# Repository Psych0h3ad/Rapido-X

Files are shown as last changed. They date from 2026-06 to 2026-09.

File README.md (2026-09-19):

# Rapido X

## P3D STEP files — English

The P3D front and rear parts feature a structure designed to make cable routing easier and gentler on the cables than the version released by Phaetus.

[See the illustrated P3D vs. Phaetus comparison](docs/P3D-vs-Phaetus.md), including a close-up of the front cable-routing cutout, the rear opening and the top-hole layout. An [experimental heatsink-cooling CFD comparison](docs/cooling/README.md) is also available.

**I am not a specialist in thermodynamics or fluid mechanics; please treat the simulation results as reference material only.** They use simplified assumptions and have not been validated by physical tests.

- [SB Front Rapido X_P3D.STEP](SB%20Front%20Rapido%20X_P3D.STEP) — Front part
- [SB Rear CW2 Rapido X_P3D.STEP](SB%20Rear%20CW2%20Rapido%20X_P3D.STEP) — Rear part for CW2

## P3D STEPファイル — 日本語

P3D版のフロント・リアパーツは、Phaetusが公開したバージョンと比べて、ケーブルを取り回しやすく、ケーブルに優しい構造になっています。

[P3D版とPhaetus公式版の図解比較](docs/P3D-vs-Phaetus.md)では、フロントのケーブル用切り欠きの拡大図に加え、リア開口部・上面の穴配置の違いを確認できます。[ヒートシンク冷却の試験的なCFD比較](docs/cooling/README.md)も掲載しています。

**私は熱力学・流体力学の専門家ではありませんので、解析結果は参考程度にご覧ください。** 簡略化した仮定に基づく結果であり、実機試験による検証は行っていません。

- [SB Front Rapido X_P3D.STEP](SB%20Front%20Rapido%20X_P3D.STEP) — フロントパーツ
- [SB Rear CW2 Rapido X_P3D.STEP](SB%20Rear%20CW2%20Rapido%20X_P3D.STEP) — CW2用リアパーツ

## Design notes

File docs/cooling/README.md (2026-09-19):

# Rapido X: P3D / Phaetus exploratory cooling comparison

2026-09-20 · OpenFOAM v2412 · SIBOOR 4010 fan installation

> **Experimental results — for reference only / 試験的な結果・参考資料**
>
> I am not a specialist in thermodynamics or fluid mechanics. Please treat this AI-assisted, exploratory CFD comparison as reference material only. It uses simplified assumptions and has not been validated by physical tests or independently reviewed by a specialist. It does not establish real-world cooling performance or a guaranteed temperature reduction.
>
> 私は熱力学・流体力学の専門家ではありません。このAI支援による試験的なCFD比較は、参考程度にご覧ください。簡略化した仮定に基づく結果であり、実機試験による検証や専門家による独立したレビューは行っていません。実機の冷却性能や温度低下を保証するものではありません。

## 日本語

**今回の仮定では、P3D版の方がヒートシンクから熱を逃がしやすい結果でした。** 同じ送風圧力で比較した放熱コンダクタンスは、25 Paで公式版より約27%高く、追加した10 Pa・50 Paの条件でも同じ傾向でした。これは実測したファン特性による性能保証や、実機の温度低下率を表すものではありません。

流れの残差は設定した収束目標に達しておらず、メッシュ独立性も未検証です。**統合した流量・放熱指標を使った探索的な比較**として扱ってください。細部の速度や実機の温度を断定する用途には使えません。

### 比較結果

同じRapido UHF用の長いMain Bodyと同じRapido X外形を使用し、フロント・リアの取り付け部品を入れ替えました。表内の数値は「Phaetus公式 / P3D」の順です。

| 仮定したファン全圧 | 入口流量 L/min（公式 / P3D） | 放熱能力 H, W/K（公式 / P3D） | P3DのHの差 |
|---|---:|---:|---:|
| 10 Pa | 39.7 / 37.9 | 0.253 / 0.323 | +28.0% |
| 25 Pa | 67.2 / 65.3 | 0.366 / 0.467 | +27.3% |
| 50 Pa | 99.1 / 97.2 | 0.473 / 0.598 | +26.4% |

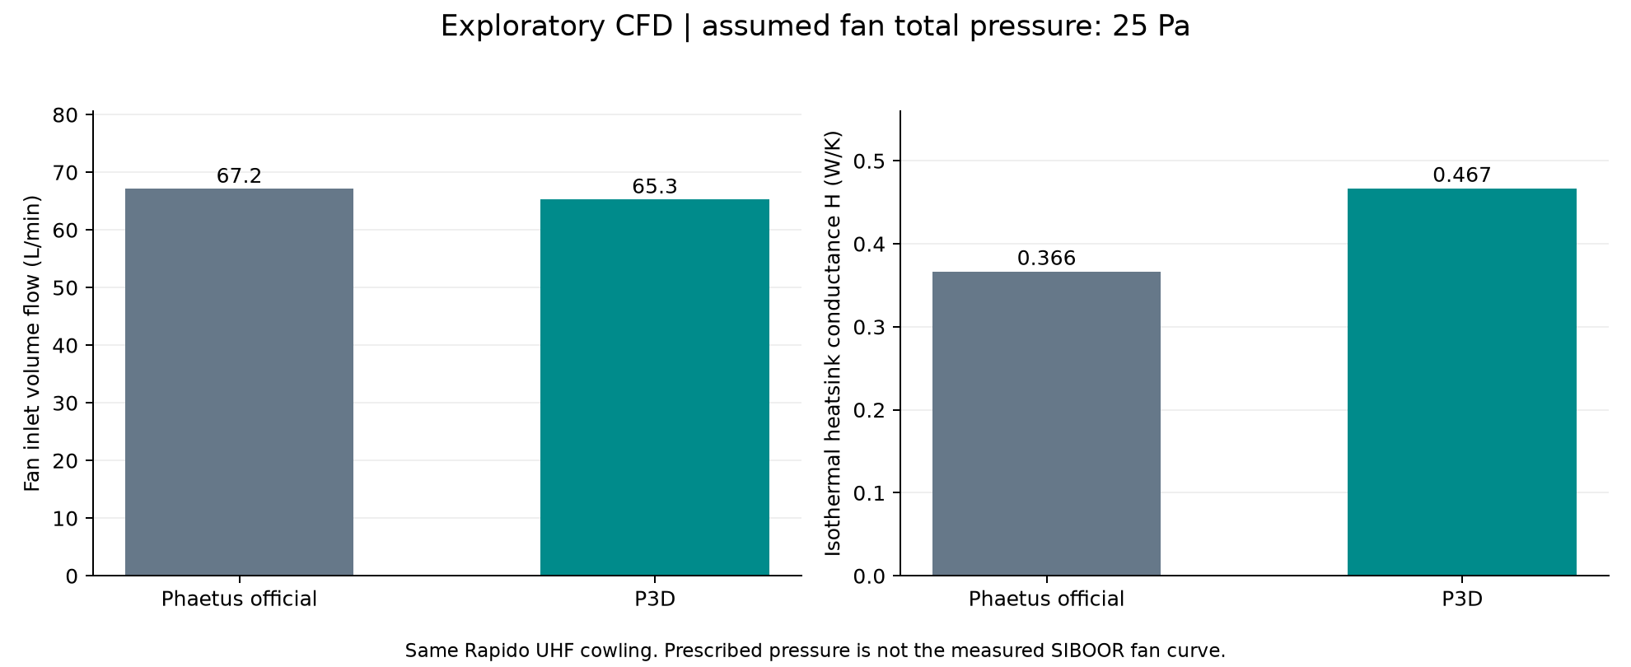
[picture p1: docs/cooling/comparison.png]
25Pa comparison


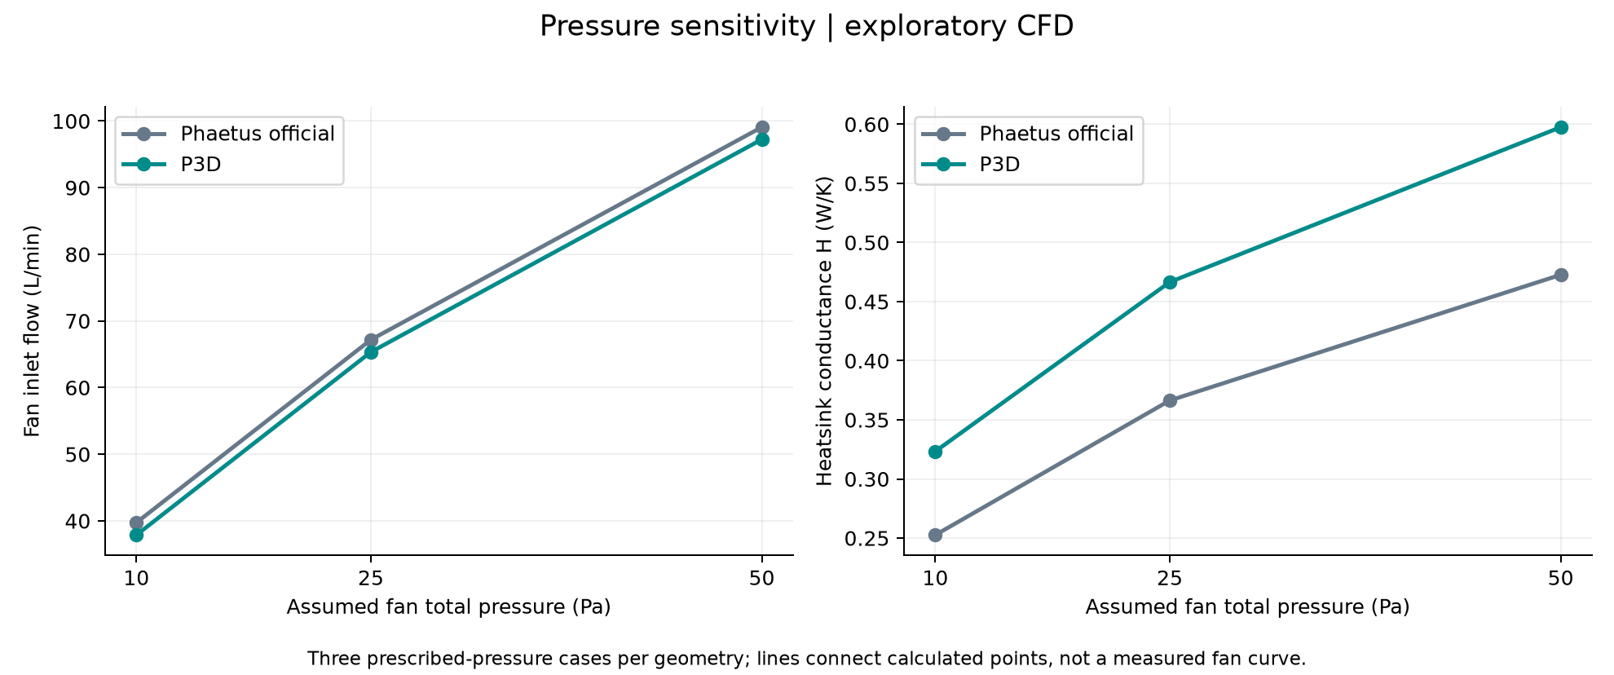
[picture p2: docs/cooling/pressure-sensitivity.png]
Pressure sensitivity


Hは、ヒートシンクと周囲の温度差1 Kあたりに空気へ逃がせる熱量を表します。計算ではヒートシンク表面を一様温度とし、`Q = H × (T_sink − T_ambient)` として比較しています。温度低下率やヒーター出力そのものではありません。

P3D版の空気に露出するヒートシンク面積は、このメッシュでは約13.4%大きくなっています。総風量の多少だけで放熱能力は決まらず、露出面積、フィン周囲への風の届き方、排気経路が合わせて影響しています。今回比較したのは前後の部品全体であり、[形状比較で示したケーブル用切り欠き](../P3D-vs-Phaetus.md)だけの効果を分離した計算ではありません。

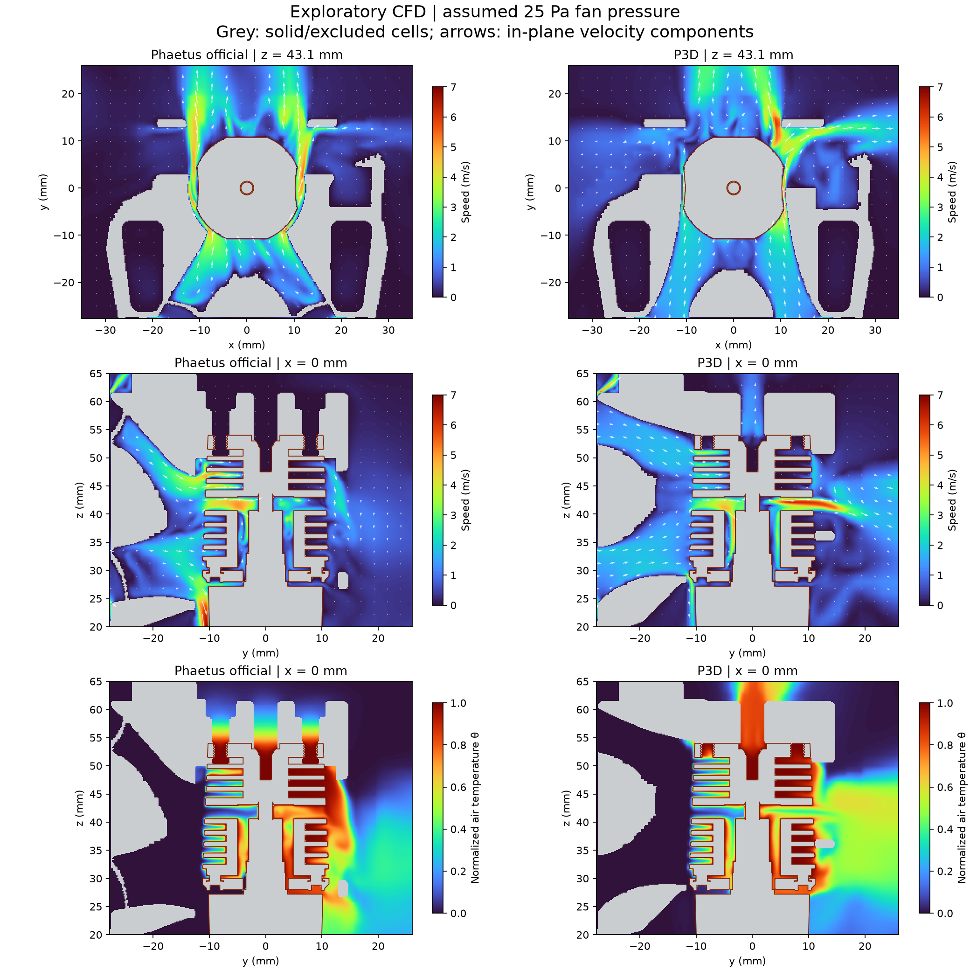
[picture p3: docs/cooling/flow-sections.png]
Flow and normalized temperature sections


断面図の矢印は3次元速度の断面内成分です。粒子の軌跡を表すものではありません。灰色は固体または計算対象外の領域、θは周囲0・ヒートシンク表面1に正規化した空気温度です。

### ブロック温度250℃・300℃との関係

250℃・300℃はヒーターブロック側の条件としました。ヒートシンク全体をこの温度にはしていません。公開STEPは材質境界まで分かれた熱解析用アセンブリではないため、ヒートブレイクや接触部の熱抵抗を直接確定できません。

そこで、CFDで得たHを使い、ブロックからヒートシンクへの熱の伝わりやすさGを変えた単純な熱回路を示します。

`T_sink = (G × T_block + H × T_ambient) / (G + H)`

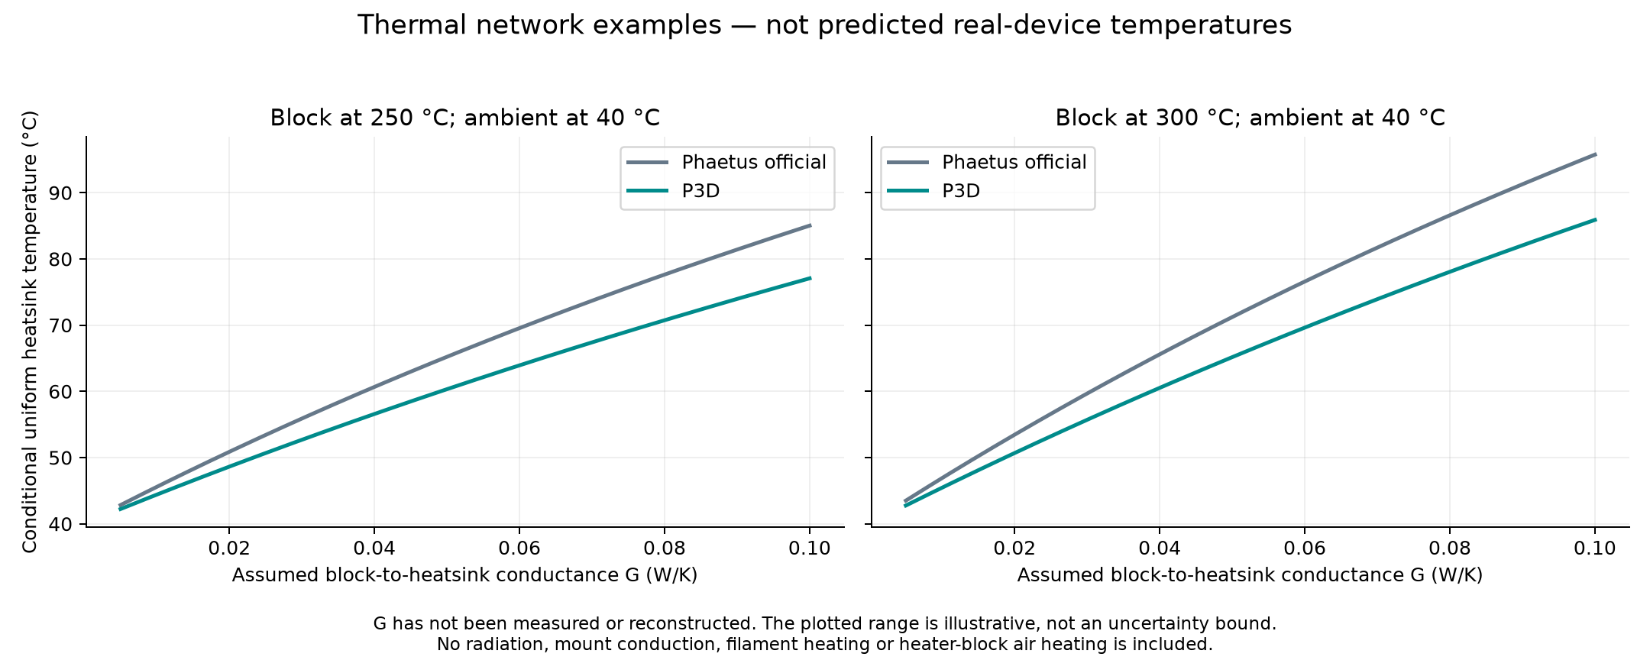
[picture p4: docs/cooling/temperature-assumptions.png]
Conditional temperature examples


例えば、**G=0.020 W/Kと仮定した場合だけ**の値は下表です。Gは実測値でもCADから復元した値でもなく、グラフの範囲も実機の誤差範囲を意味しません。周囲温度は40℃、ファン条件は25 Paです。

| ブロック | 公式の仮定温度 | P3Dの仮定温度 | 仮定上の差 |
|---|---:|---:|---:|
| 250°C | 50.9°C | 48.6°C | 2.2°C |
| 300°C | 53.5°C | 50.7°C | 2.8°C |

120 Wは板状セラミックヒーターの定格であり、温度制御中に常時120 Wがヒートシンクへ流入する設定にはしていません。上の値は連成熱伝導解析で求めた実機温度ではありません。

### 計算条件と限界

- ファンはユーザー指定のSIBOOR `4010-2401-8000-SS`、24 V・0.1 A、約8000 rpmを想定。実測P–Q曲線は入手できていないため、10/25/50 Paを仮定した圧力入口で比較しました。羽根回転・旋回流・実際の動作点は再現していません。
- 4010モデルの出口位置に、外半径18.5 mm・ハブ半径9 mmの環状入口を設定。寸法は汎用CADを基にした近似です。
- 周囲40℃、密度1.13 kg/m³、動粘度1.7×10⁻⁵ m²/s、比熱1006 J/(kg K)、Pr=0.71、乱流Pr=0.85を使用。一定物性の非圧縮・強制対流モデルです。
- 等温の冷却対象面は、組立座標で x/y=±20 mm、z=30.49–54.01 mmに入るホットエンド表面を選択したヒートシンク代表領域です。下端の接続部を含む残りのホットエンド外形は断熱としており、全外表面の放熱量ではありません。
- `simpleFoam`、定常RANS k–ω SST。25 Paは500反復、10/50 Paはスケーリングした25 Paの場から120反復。温度場は各条件の流れを固定し、さらに収束させています。
- 固体内部の熱伝導、接触熱抵抗、放射、浮力、ヒーターブロックから空気への直接放熱、フィラメントへの熱流を含みません。ヒートシンクは一様温度面として扱い、アルミの具体的な熱伝導率を解いていません。
- 配線、取り付けねじ、PTFEチューブ、押出機周りの追加の遮蔽物は再現していません。5015のパーツ冷却の送風・ファン形状も含みません。実際の組み立て状態による閉塞は、特に大きい開口の効果を変える可能性があります。
- 外部領域は x=±55、y=−27.9〜45、z=−22〜82 mmで、UHFボディ上部は領域外です。領域寸法の感度は未検証です。
- Phaetus仕様ではヒーターブロックはニッケルめっき銅合金、ヒートブレイクはステンレス＋EndCoatです。この仕様情報を、固体の材質別連成解析を実施したという意味には用いていません。

### 数値検証

| 項目 | 結果 |
|---|---|
| セル数 | 公式 1,897,926 / P3D 2,041,284 |
| フィン付近の基準セル幅 | 約0.25 mm。境界層プリズム層なし |
| 最大非直交角 | 公式66.24° / P3D63.21° |
| メッシュ警告 | 両モデル各1個の高skewness面（約7.77）。標準checkMeshは1項目未合格 |
| 警告位置 | P3Dでは x≈28.7, y≈−2.37, z≈16.3 mm。ヒートシンク領域の外側 |
| 全6条件の最大流量収支誤差 | 0.0066% |
| 全6条件の最大熱収支誤差 | 0.0116% |
| 追加収束したθの最大最終初期残差 | 9.02e-09 |
| 最後の6記録の最大入口流量変動幅 | 0.205% |
| 最後の6記録の最大放熱モニター変動幅 | 0.512%（追加温度収束前） |

流れの残差目標1e−5は全項目で達成しておらず、周囲の再循環に揺れが残ります。上記の変動幅は反復間の安定性であり、実機に対する誤差率ではありません。別解像度でのメッシュ独立性試験、ファン曲線による動作点の検証、実機温度との照合は未実施です。

入力メッシュは小さい穴や継ぎ目を修復しています。フロント修復による体積差は0.02%未満、修復面から原形状へのサンプル最大距離はP3D約0.188 mm、公式約0.269 mmでした。ホットエンドの修復では内部ボア付近に最大約1.80 mmの差があるサンプルがあり、体積差は約0.136 mm³でした。これらはサンプル評価であり、厳密な誤差上限ではありません。元のSTEP/3MFを変更していません。

### 実機で確認するなら

同じファン・同じ電圧、同じチャンバー温度、同じ配線経路で、ブロック250℃と300℃それぞれの安定後にヒートシンクの同じ位置を測ると、この比較の方向を検証できます。今回のCFDだけから、実機で何℃下がるか、ヒートクリープが必ず解消するかは判断できません。

## English

**Under the assumptions tested here, the P3D assembly has higher isothermal heatsink-to-air conductance than the Phaetus assembly.** At an assumed fan total pressure of 25 Pa, the calculated difference is approximately 27%. The direction remains the same at 10 and 50 Pa. This is an exploratory result, not a validated performance claim for the actual SIBOOR fan.

The table above reports inlet volume flow and conductance H; each pair is **Phaetus / P3D**. H relates heat removal to heatsink-to-ambient temperature difference through `Q = H(T_sink − T_ambient)`. It is not a percentage reduction in operating temperature.

Both assemblies use the same long Rapido UHF cowling and Rapido X outer geometry. The entire front/rear mount pair is exchanged, so this study does not isolate the effect of only the highlighted cable cutout. The P3D case exposes more heatsink surface to air. Actual wires, fasteners, PTFE tubing and additional extruder obstructions are omitted.

The fan is represented by a prescribed annular pressure inlet. The tested 10/25/50 Pa values are assumptions, not a measured P–Q curve or an 8000 rpm rotor simulation. Air is modeled at 40°C using steady incompressible k–ω SST RANS. The isothermal sink region is selected from hotend faces within x/y=±20 mm and z=30.49–54.01 mm; the remaining hotend envelope, including the lower connection region, is adiabatic. Each temperature field is additionally converged on its frozen flow field, with a maximum heat balance discrepancy of 0.0116% across the six cases.

The 250°C and 300°C heater-block conditions are illustrated with a separate lumped thermal network using the CFD conductance. The block-to-heatsink conductance G is unknown. The temperature plot and example table therefore show **conditional scenarios, not predicted device temperatures**. The 120 W ceramic-heater rating is not treated as continuous heatsink heat input. Solid conduction, contact resistances, radiation, buoyancy and direct heater-block heating of the air are omitted.

The specified flow residual target was not reached, and mesh independence and experimental validation have not been demonstrated. One high-skewness face is flagged in each mesh; other reported mesh checks pass. Integrated quantities stabilize, but residual recirculation fluctuations remain. These limitations must accompany any reuse of the numbers or figures.

## Sources and files

- [User repository and CAD](https://github.com/Psych0h3ad/Rapido-X): `SB Front Rapido X_P3D.STEP`, `SB Rear CW2 Rapido X_P3D.STEP`, `Rapido X.STEP`, `Rapido X-voron.3mf`.
- Official comparison meshes: `3D/Objects/object_2.model` mesh 1 (front), `3D/Objects/object_3.model` mesh 3 (rear), within the supplied Phaetus 3MF.
- [Voron Stealthburner CAD](https://github.com/VoronDesign/Voron-Stealthburner/tree/8bcb9c246fac19d8ac03931ef97fa07c5e5f0f2b/CAD): 4010 fan position/reference geometry.
- [Rapido UHF long cowling](https://github.com/VoronDesign/VoronUsers/tree/8e5067f4f6457da8a552983dd210ec48c40be2ca/printer_mods/bythorsthunder/Stealthburner_Rapido_Uhf): bythorsthunder's VoronUsers mod.
- [Phaetus Rapido X specifications](https://www.phaetus.com/products/rapido-x): heater and material information.
- [SIBOOR bill of materials](https://docs.siboor.com/siboor-trident-june/bill-of-materials): 24 V / 8000 rpm 4010 fan reference, not an exact-part pressure curve.
- [OpenFOAM scalar transport documentation](https://api.openfoam.com/2312/classFoam_1_1functionObjects_1_1scalarTransport.html): passive scalar transport with molecular/turbulent diffusivity.
- [metrics.json](metrics.json): 25 Pa values.
- [pressure-sensitivity.csv](pressure-sensitivity.csv) / [JSON](pressure-sensitivity.json): all six runs.
- [assumptions.json](assumptions.json) and [source-manifest.json](source-manifest.json): assumptions and input file hashes.
- [Validation records](validation/README.md): solver, mesh and thermal-balance records; machine hostname and local workspace path have been redacted.
- [simulation-inputs.zip](simulation-inputs.zip): geometry, settings and a run script for rebuilding the comparison. This reproduces the setup with OpenFOAM v2412; the original baseline initially used v1912, so the archive does not promise a bit-for-bit identical iteration history.

Photographs of the physical assembly were used as setup references and are not included here.

[Back to repository README / リポジトリのREADMEに戻る](../../README.md)

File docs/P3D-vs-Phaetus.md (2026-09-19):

# P3D vs. Phaetus: cable-routing geometry
# P3D版とPhaetus公式版：ケーブル取り回しに関わる形状の比較

The P3D parts are designed to make cable routing easier and gentler on the cables than the Phaetus version. The main feature highlighted here is the **front-side cutout directly above the lower mounting hole**, shown on the left side of the part in the interior view below. The rear part also has a large side cutout.

P3D版は、Phaetus公式版よりケーブルを取り回しやすく、ケーブルに優しい構造を目指しています。特に注目しているのは、**フロントの下側取付穴のすぐ上にある側面の切り欠き**です。下の内側から見た図ではパーツの左側にあたります。リア側にも大きな側面切り欠きがあります。

Here, **Phaetus** means the VORON parts contained in this repository's [Rapido X-voron.3mf](../Rapido%20X-voron.3mf). **P3D** means the two STEP files linked below. This comparison applies to these specific files.

本資料の **Phaetus公式版** は、このリポジトリの [Rapido X-voron.3mf](../Rapido%20X-voron.3mf) に含まれるVORON用パーツを指します。**P3D版** は下記2点のSTEPファイルです。比較対象はこれらのファイルに限定しています。

- [SB Front Rapido X_P3D.STEP](../SB%20Front%20Rapido%20X_P3D.STEP)
- [SB Rear CW2 Rapido X_P3D.STEP](../SB%20Rear%20CW2%20Rapido%20X_P3D.STEP)

## 1. Main change: front cable-routing cutout / 主な変更：フロントのケーブル用切り欠き

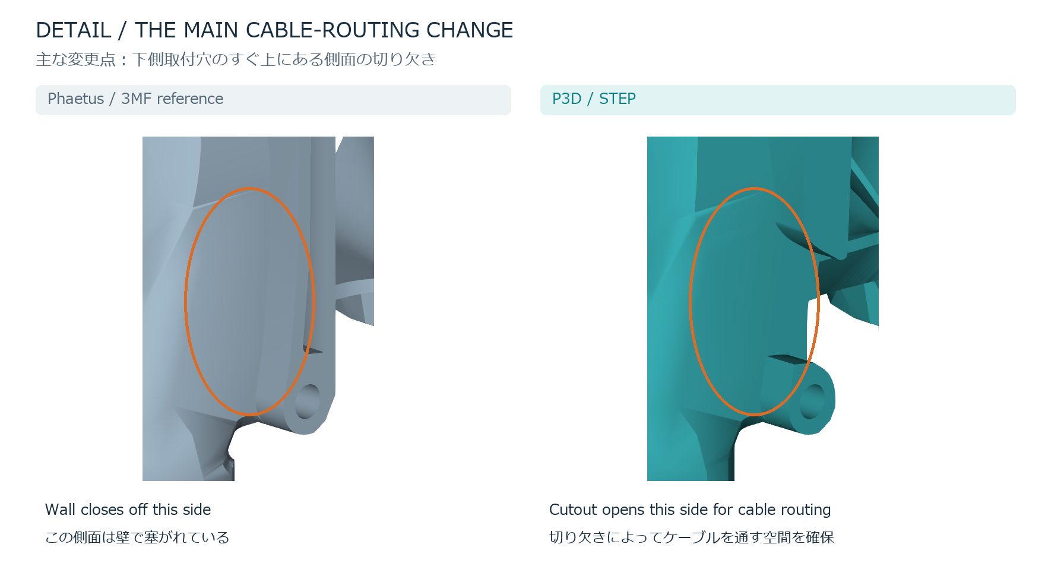
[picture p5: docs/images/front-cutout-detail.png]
Main cable-routing change: close-up of the front-side cutout above the lower mounting hole / 主な変更点：フロント下側取付穴の上にある側面切り欠きの拡大比較


**English:** The Phaetus reference has a continuous wall immediately above the lower mounting hole. P3D cuts away this section, creating a side opening for cable routing. This is the main area intended to make cable positioning easier and reduce the need to route cables around the continuous wall.

**日本語：** 公式版では、下側の取付穴のすぐ上まで壁が連続しています。P3D版ではこの部分を切り欠き、ケーブルを通すための側面開口を設けています。連続した壁を回り込ませる必要を減らし、ケーブルを配置しやすくすることを意図した主な変更箇所です。

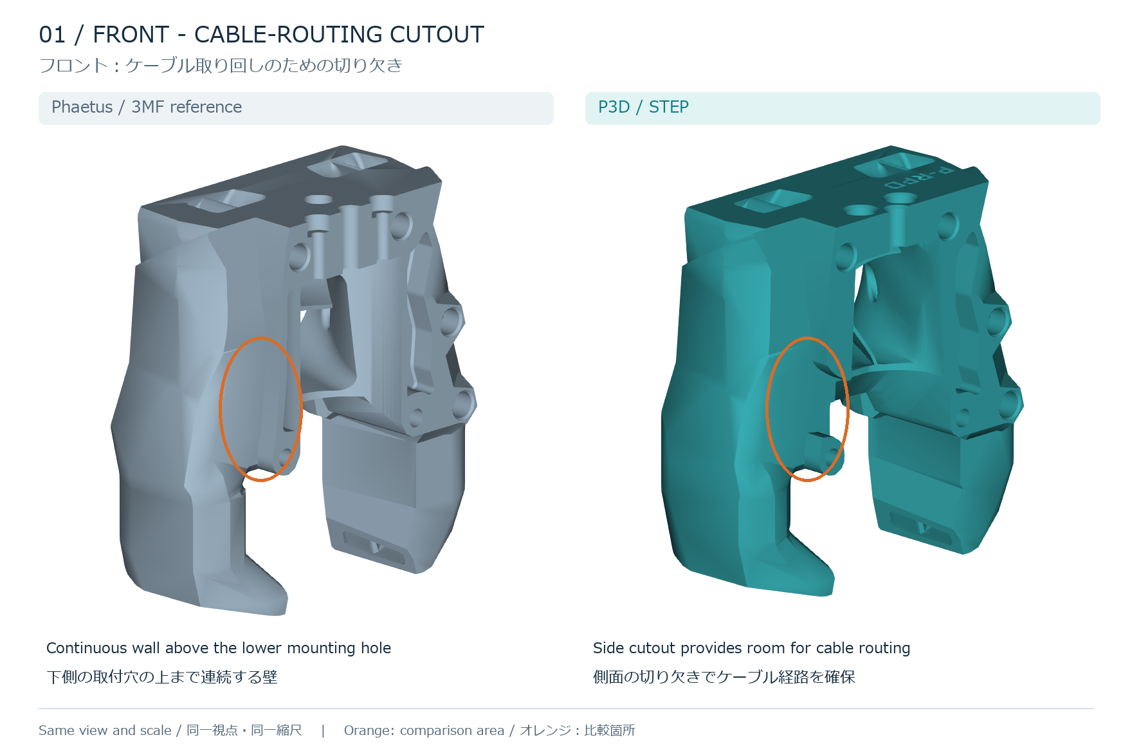
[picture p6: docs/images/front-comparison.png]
Front overview highlighting the same cable-routing cutout / 同じケーブル用切り欠きを示したフロント全体図


## 2. Rear: open side access / リア：側方への開放

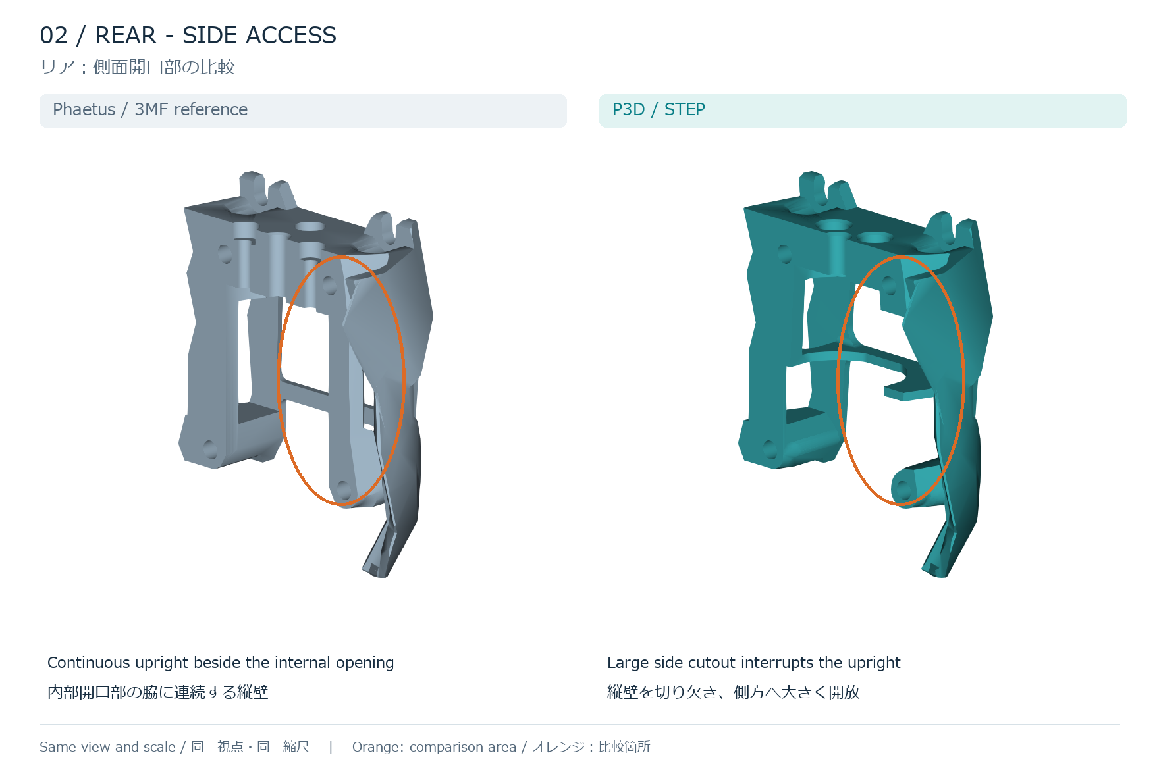
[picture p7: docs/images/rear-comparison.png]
Rear comparison: continuous upright in the Phaetus reference and a large side cutout in P3D / リア比較：公式版の連続した縦壁とP3D版の側面切り欠き


**English:** In the highlighted area, the Phaetus reference has a continuous upright between the upper and lower mounting regions. In P3D, a large cutout interrupts that upright, opening the cavity toward the side. This is the clearest visible change relevant to cable access and positioning.

**日本語：** オレンジで囲んだ部分では、公式版は上側と下側の取付部の間に縦壁が連続しています。P3D版はこの縦壁を大きく切り欠き、内部空間を側方へ開放しています。ケーブルへのアクセスや配置に関わる、最も分かりやすい形状変更です。

## 3. Other visible changes / その他の形状差

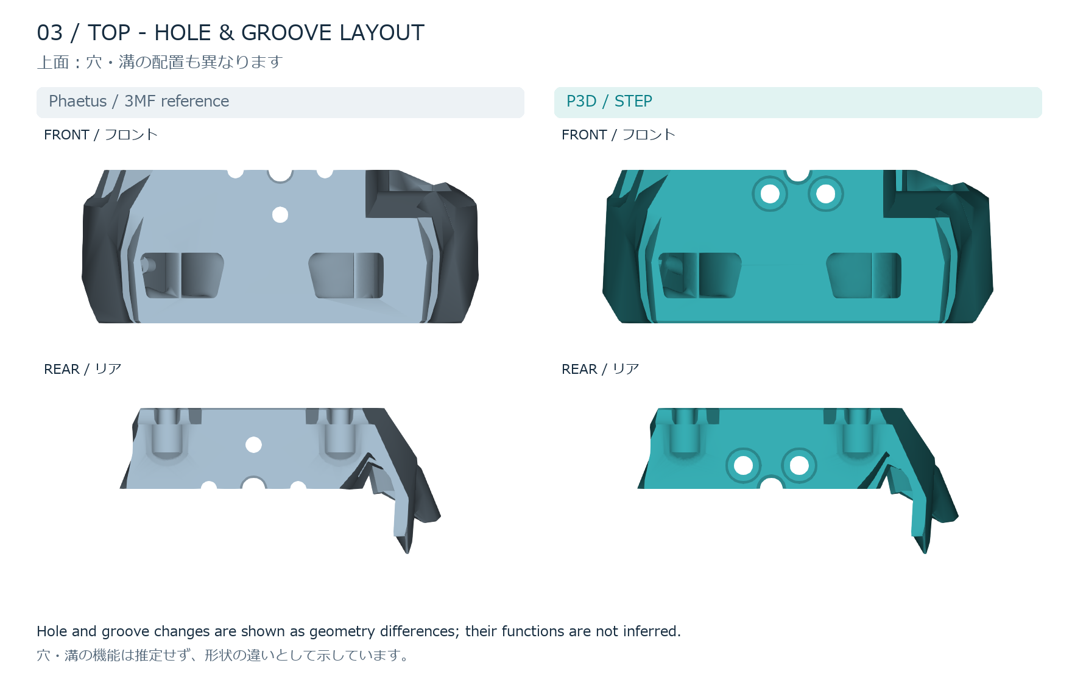
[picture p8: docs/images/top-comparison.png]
Top-view comparison of holes and grooves in the front and rear parts / フロント・リアの上面穴と溝の比較


**English:** The top-hole arrangement and the grooves along the mating edge also differ. The reference has three visible grooves along this edge; P3D retains the central groove and changes the surrounding hole arrangement. The front model also differs around the fan and lower outline. The P3D files therefore contain additional geometry changes beyond the highlighted cable-access areas. The functions of individual holes are not assigned from appearance alone.

**日本語：** 上面の穴配置と合わせ面側の溝形状にも違いがあります。公式版にはこの縁に3本の溝が見えますが、P3D版では中央の溝を残し、その周辺の穴配置が変更されています。フロントにはファン周辺や下側の輪郭にも差があります。P3D版は、強調したケーブルアクセス部分以外にも形状変更を含みます。個々の穴の用途は、外観だけから断定していません。

## Heatsink cooling: experimental CFD / ヒートシンク冷却：試験的なCFD比較

An [exploratory CFD comparison](cooling/README.md) is now available, including flow sections, numerical results and the assumptions used. **I am not a specialist in thermodynamics or fluid mechanics; please treat it as reference only.** Physical cooling tests have not been performed, the specified flow residual target was not reached, and mesh independence remains unverified.

流れの断面図・計算結果・仮定条件をまとめた[試験的なCFD比較](cooling/README.md)を掲載しました。**私は熱力学・流体力学の専門家ではありませんので、参考程度にご覧ください。** 実機での冷却試験は未実施で、設定した流れの収束目標は未達、メッシュ独立性も未検証です。

**English:** Easier cable routing does not establish better cooling from the Stealthburner's 4010 heatsink fan. If an opening lets air bypass the heatsink fins, it can reduce useful cooling flow; if it relieves a restriction after the air passes through the fins, it can help. Which effect dominates depends on the assembled hotend, fan, duct and cable placement. Fan airflow also depends on the resistance of the complete flow path ([Noctua: fan operating points and airflow resistance](https://www.noctua.at/en/expertise/tech/nf-a12x25-performance-comparison-to-nf-f12-and-nf-s12a)). The geometry comparison alone does not establish which version cools better; the separate CFD report gives conditional, exploratory results.

**日本語：** ケーブルを取り回しやすいことと、Stealthburnerの4010ファンによるヒートシンク冷却が優れていることは別です。開口からフィンを通らずに風が逃げる場合は有効な冷却風量が減る可能性があり、フィン通過後の排気抵抗を減らす場合は有利に働く可能性があります。どちらが支配的かは、ホットエンド・ファン・ダクト・配線を組み付けた状態によります。また、ファンの風量は流路全体の抵抗によって変わります（[Noctuaによるファンの動作点と通風抵抗の解説](https://www.noctua.at/en/expertise/tech/nf-a12x25-performance-comparison-to-nf-f12-and-nf-s12a)）。形状比較だけでは、どちらの冷却性能が優れているかは判断できません。条件付きの試験的な計算結果は、別ページのCFD資料にまとめています。

**Suggested A/B check / 比較方法：** Use the same fan, drive setting, hotend temperature, chamber temperature, cable placement and extrusion conditions. Measure the stabilized temperature at the same point on the heatsink near the heatbreak; nozzle temperature alone does not measure heatsink cooling. Repeat with the two versions. / 同一ファン・同一駆動条件・同一ホットエンド温度・同一チャンバー温度・同じ配線位置と押出条件で比較します。ヒートブレイクに近いヒートシンクの同じ位置で、温度が落ち着いてから測定し、両形状で繰り返します。ノズル温度だけではヒートシンクの冷却性能を判断できません。

## Sources and comparison method / 比較元と作成方法

| Part / パーツ | Phaetus reference inside 3MF / 3MF内の比較元 | P3D file / 比較先 |
| --- | --- | --- |
| Front / フロント | `3D/Objects/object_2.model`, mesh object `1`; name `前座接近开关` | `SB Front Rapido X_P3D.STEP` |
| Rear / リア | `3D/Objects/object_3.model`, mesh object `3`; name `后座` | `SB Rear CW2 Rapido X_P3D.STEP` |

**English:** Images were rendered directly from the 3MF meshes and STEP geometry. Print-bed placement transforms were excluded; the reference parts were translated into a common display frame without rotation, scaling or deformation. Each left/right pair uses the same camera and scale. Grey identifies the Phaetus reference, teal identifies P3D, and orange outlines mark the areas discussed; colors are not a distance map. The images show geometry differences, not an installed cable test. Cable bend radius, pulling force, durability and complete assembly fit were not measured.

**日本語：** 図は3MFのメッシュとSTEPの形状から直接作成しました。印刷プレート上の配置変換は使わず、比較元を平行移動して表示位置を合わせています。形状の回転・拡大縮小・変形は行っていません。各図の左右は同じ視点・縮尺です。灰色は公式版、青緑はP3D版、オレンジの囲みは説明対象の箇所を示し、色は距離分布を表していません。本資料は形状比較であり、実際に配線した状態の試験ではありません。ケーブルの曲げ半径・引張力・耐久性や、組立全体の適合性は測定していません。

[Back to README / READMEに戻る](../README.md)

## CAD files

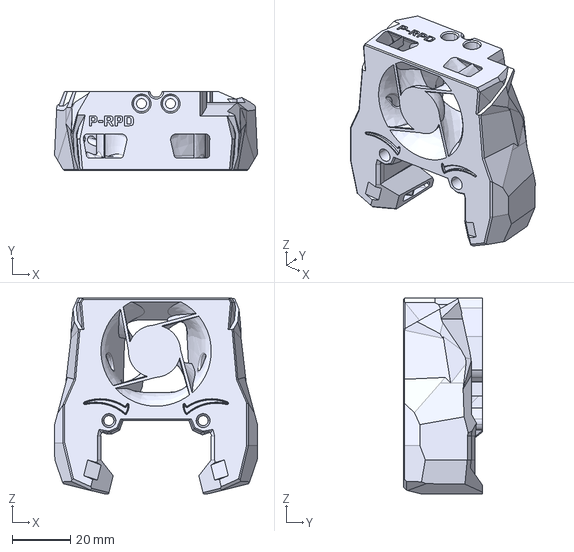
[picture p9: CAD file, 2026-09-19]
SB Front Rapido X_P3D.STEP
70.0 x 27.4 x 67.4 mm

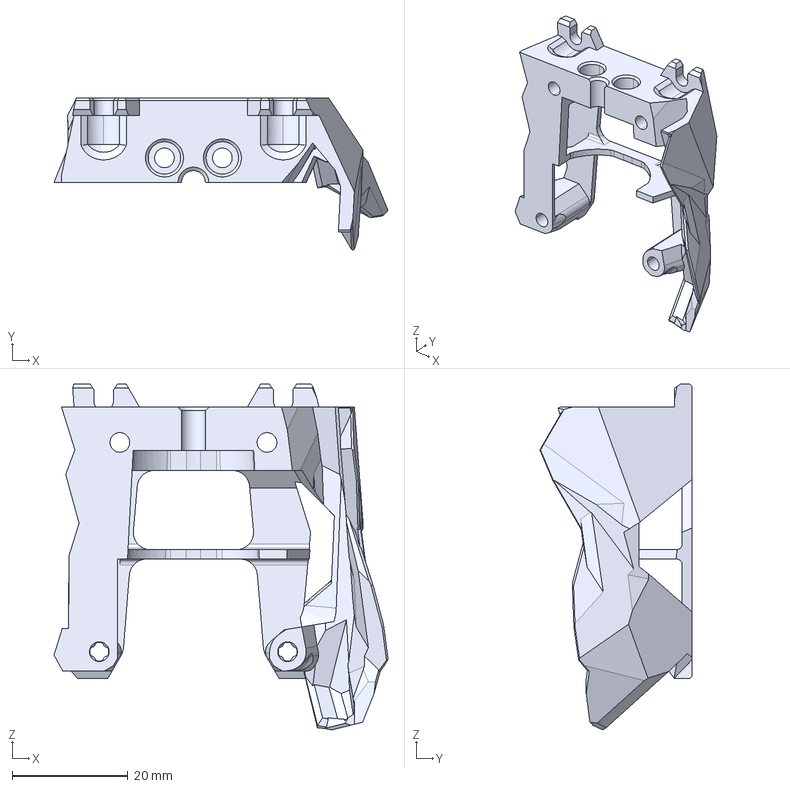
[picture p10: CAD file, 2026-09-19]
SB Rear CW2 Rapido X_P3D.STEP
57.7 x 26.3 x 59.7 mm

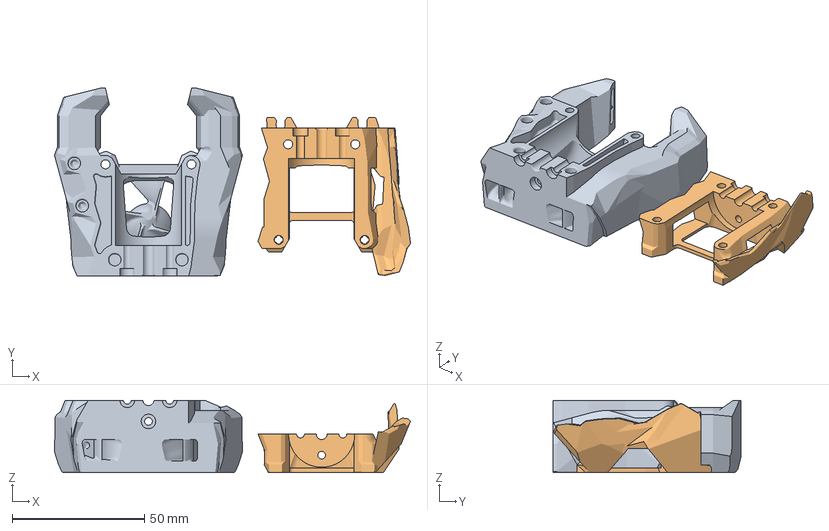
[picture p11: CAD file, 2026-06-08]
Rapido X-voron.3mf
134.6 x 71.0 x 27.4 mm
前座接近开关
后座

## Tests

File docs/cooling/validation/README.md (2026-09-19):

# Validation records / 計算の検証記録

These files document the exploratory runs described in the [report](../README.md). They do not validate real-world cooling performance. The specified flow residual target was not reached, and each mesh has one high-skewness warning.

このフォルダーには[比較資料](../README.md)の試験的な計算記録を掲載しています。実機性能を保証するものではありません。設定した流れの残差目標は未達で、各メッシュに高skewness面の警告が1件あります。

- `*-thermal-audit.csv`: patch areas, volume flow and heat balance for all six runs / 6条件の面積・流量・熱収支。
- `*-thermal-convergence.log`: additional scalar convergence on the frozen flow / 流れを固定した温度場の追加収束。
- `*-flow.log`: 25 Pa baseline flow and scalar iteration records / 25 Paの基準計算記録。
- `*-mesh-check.log`: mesh checks, including the remaining warning / 未解消の警告を含むメッシュ検査。
- `geometry-repair.json` and `hotend-repair-location.json`: sampled geometry repair checks / メッシュ修復のサンプル比較。

In the logs, only the machine hostname and local workspace path were replaced with `REDACTED_HOST` and `<CFD_WORKSPACE>`. Numerical solver output has not been changed.

ログ内の計算機名とローカル作業パスのみ、それぞれ `REDACTED_HOST` と `<CFD_WORKSPACE>` に置き換えています。計算値は変更していません。

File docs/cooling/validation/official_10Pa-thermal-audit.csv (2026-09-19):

patch | area_m2 | volume_out_m3_s | advected_out_W_K | diffusive_in_W_K
frontPlane | 0.00877747132036 | 4.56851773377e-05 | 1.52320775643e-06 | -6.68693860976e-05
atmosphere | 0.0422038112657 | 0.000616491838052 | 0.249572401044 | -0.00293962421399
body | 0.00675752446126 | 0 | 0 | 0
hotend | 0.00344808017466 | 0 | 0 | 0
front | 0.0234139419801 | 0 | 0 | 0
rear | 0.00757623900891 | 0 | 0 | 0
fanInlet | 0.000820213378393 | -0.000662195320577 | 0 | -1.74766838412e-13
fanFrame | 0.000785593969521 | 0 | 0 | 0
heatSink | 0.00645940659354 | 0 | 0 | 0.252586309091

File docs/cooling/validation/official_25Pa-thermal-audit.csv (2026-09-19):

patch | area_m2 | volume_out_m3_s | advected_out_W_K | diffusive_in_W_K
frontPlane | 0.00877747132036 | 6.71649709062e-05 | 1.46606570527e-07 | -1.10498897345e-06
atmosphere | 0.0422038112657 | 0.00105236300989 | 0.363732074729 | -0.00263483507581
body | 0.00675752446126 | 0 | 0 | 0
hotend | 0.00344808017466 | 0 | 0 | 0
front | 0.0234139419801 | 0 | 0 | 0
rear | 0.00757623900891 | 0 | 0 | 0
fanInlet | 0.000820213378393 | -0.00111960133573 | 0 | -9.2199004486e-15
fanFrame | 0.000785593969521 | 0 | 0 | 0
heatSink | 0.00645940659354 | 0 | 0 | 0.366405509134

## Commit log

2026-09-19 Add P3D front and rear STEP files with bilingual cable routing notes
    [SB Front Rapido X_P3D.STEP, SB Rear CW2 Rapido X_P3D.STEP]
2026-09-19 Document P3D cable-routing cutout with bilingual geometry comparisons
2026-09-19 Publish exploratory cooling study with bilingual reference-only notices
    [official_10Pa-thermal-audit.csv, official_25Pa-thermal-audit.csv, official_50Pa-thermal-audit.csv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]
